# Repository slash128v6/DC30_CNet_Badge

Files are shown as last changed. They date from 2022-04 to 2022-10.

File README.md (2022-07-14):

DEF CON 30 CompuNet Badge

Check out the Docs folder...

Here is an informational 'BadUSB'course from the creator of the WiFi Duck: https://learnbadusb.com/ (we are not affiliated and we don't make any money on this)



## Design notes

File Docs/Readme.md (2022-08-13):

# Flux Capacitor LED Badge

The Flux Capacitor LED badge features three microcontrollers, nine LEDs and a [SAO port](https://hackaday.com/2019/03/20/introducing-the-shitty-add-on-v1-69bis-standard/) that can be used for daughter boards (add-ons). The top two microcontrollers are Arduino Pro Micros, the bottom controller is an ESP8266 D1 Mini with Wifi capabilites. See the appendix for pinouts of each board. 

Looking at the back of the board (battery side) the Pro Micro on the left side will be programmed to control the LED lights. The Pro Micro on the right and the D1 Mini are used as a functioning [Wifi Duck](https://wifiduck.com/).

###Front of Badge:

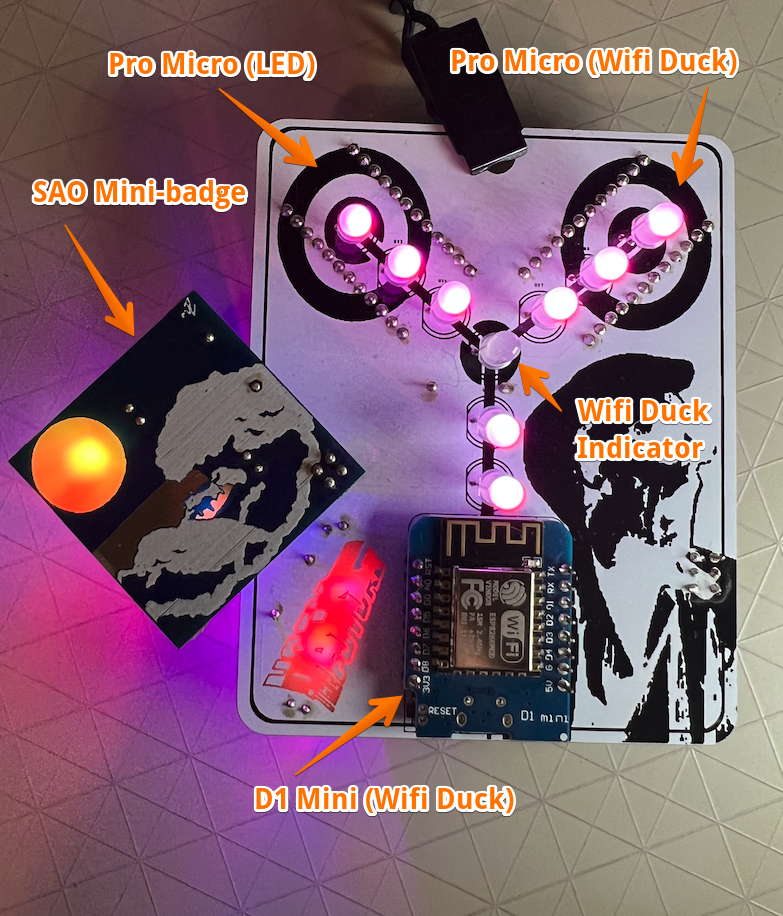
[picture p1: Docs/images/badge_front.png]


###Back of Badge:

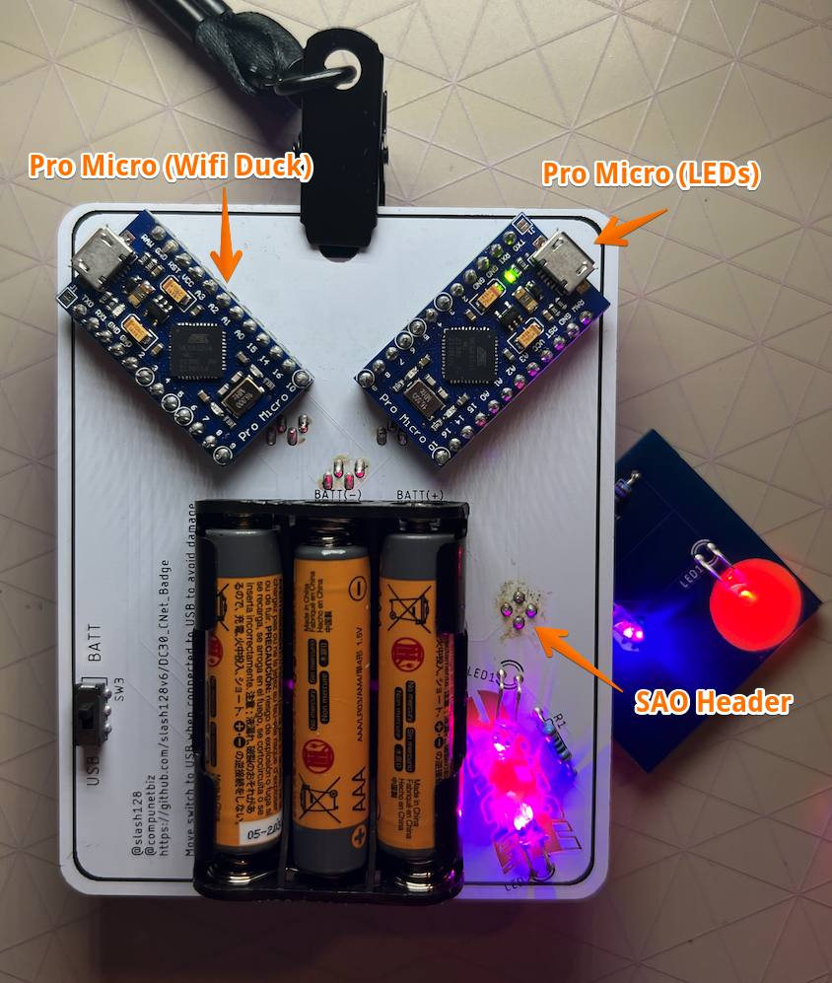
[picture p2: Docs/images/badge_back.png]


## GitHub: [https://github.com/slash128v6/DC30\_CNet\_Badge](https://github.com/slash128v6/DC30_CNet_Badge)

### Parts List

**Main Badge**

- 1 main PCB (white)
- 1 foam pad
- 3 AAA batteries
- 1 battery carrier
- 2 Pro Micro
- 1 D1 Mini
- 1 jumper socket (four pin)
- 1 on/off switch
- 1 100ohm resistor
- 9 RGB LED (larger) F5-F
- 2 RGB LED (smaller - slow cycle) PN 1196
- 1 large static bag

**Mini Badge**

- 1 aux PCB (blue)
- 1 RGB LED (smaller - slow cycle) PN 1196
- 1 RGB LED (smaller - fast cycle) PN 1197 - behind cow
- 1 jumper header (four pin)
- 1 100ohm resistor
- 1 small static bag

# Instructions

## Main Badge

### Step 1: Verify the slow-cycling LEDs (mini-badge uses fast-cycling LED)

The main badge uses 9 large RGB LEDS (with four legs) and 2 smaller slow-cycling RGB LEDs. The mini-badge uses 1 slow-cycling LED and 1 fast-cycling LED that is identical in size and shape to the slow-cycling LEDs. You can verify that you are using the correct LED by testing with the battery pack. The fast-cycling RGB will change color very rapidly - if the colors change gradually, you're using the correct LEDs for the main badge. These LEDs are internally current limited so you can test by connecting it to the battery pack as shown with the longer lead to the left (+ or anode). Do not test regular LEDs like this, they will fry. Even though they don't need a resistor do not connect them backwards or they will fry. Set aside the fast-cycling LED. The other 3 are slow-cycling LEDs.

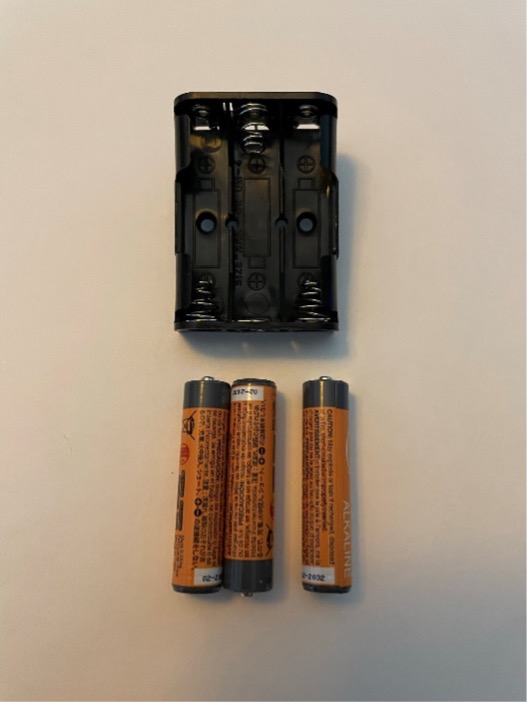
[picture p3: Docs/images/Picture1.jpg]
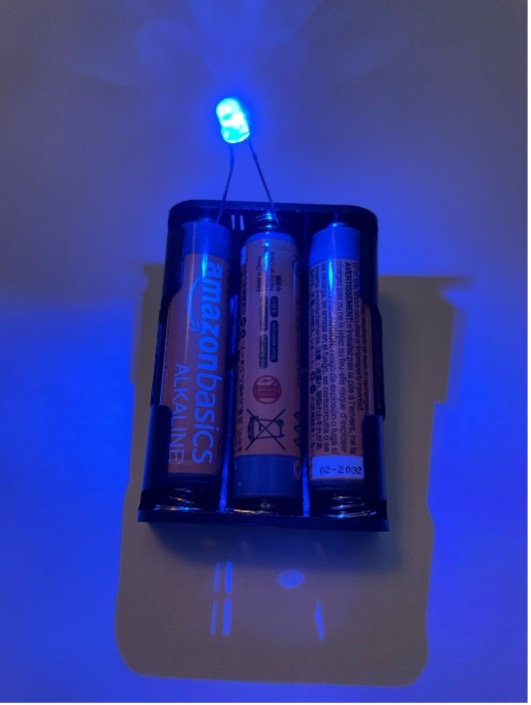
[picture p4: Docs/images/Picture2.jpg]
 

With the board upside down (silkscreen facing down), solder 2 of the slow-cycling rear LEDs on the back with short lead (- cathode) on the left side, and  flat facing label LED1 & LED2. Bend the LEDs so they are flat against the back of the board to shine through the translucent area on the PCB. Solder R1 on the back. Trim the leads on the front.

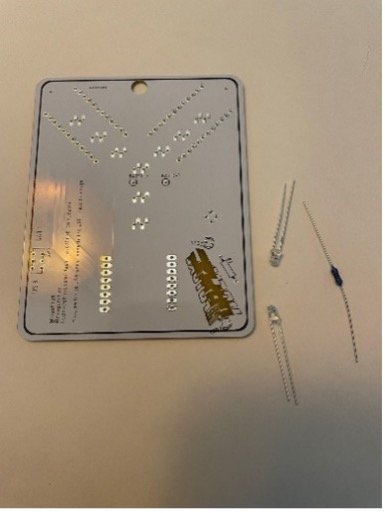
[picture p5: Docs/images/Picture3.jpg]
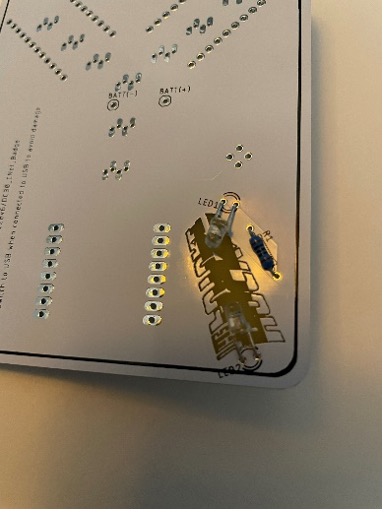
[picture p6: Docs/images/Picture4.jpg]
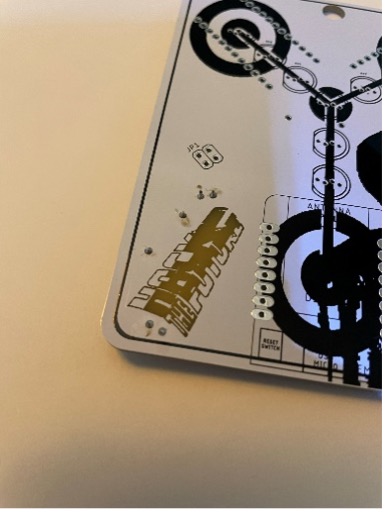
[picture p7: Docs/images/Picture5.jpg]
 

### Step 2: Solder the switch and female header

Solder the switch on the back

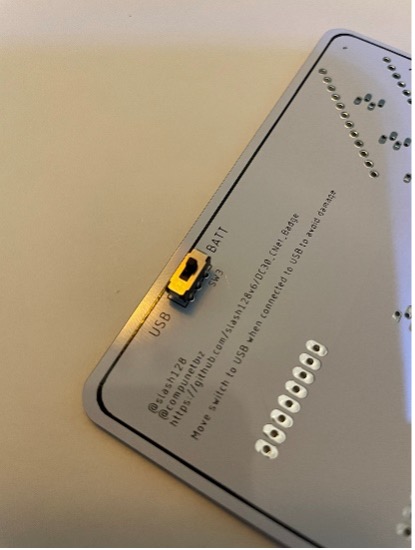
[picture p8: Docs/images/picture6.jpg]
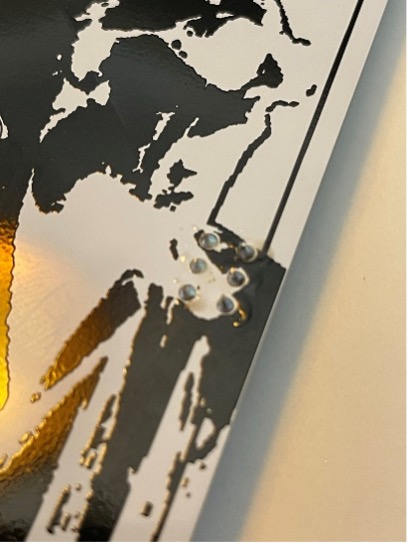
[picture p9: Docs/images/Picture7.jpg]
 

Flip the PCB over to the front and solder the SAO 4 pin female header on the front in position JP1

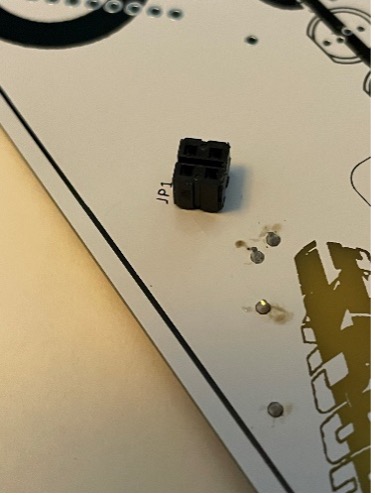
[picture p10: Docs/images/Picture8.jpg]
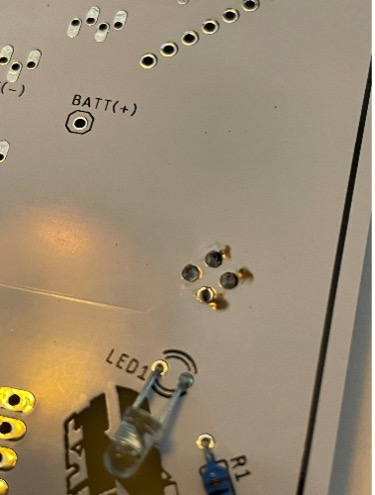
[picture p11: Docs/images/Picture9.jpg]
 

### Step 3: Install front RGB Leds

Install front RGB LEDs with long leads and flat on the left, matching the symbol on the board. Do not push all the way in, stop at the marks on the leads. Make sure there are no solder bridges. Trim the leads so there is clearance for the micro controllers to install on the other side.

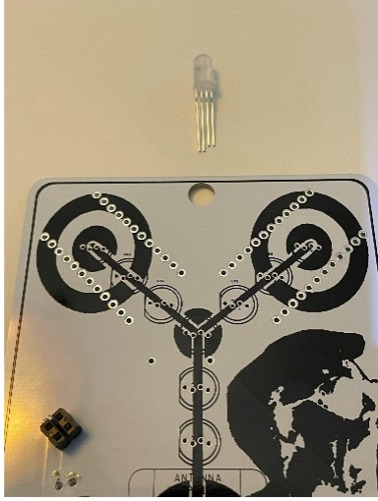
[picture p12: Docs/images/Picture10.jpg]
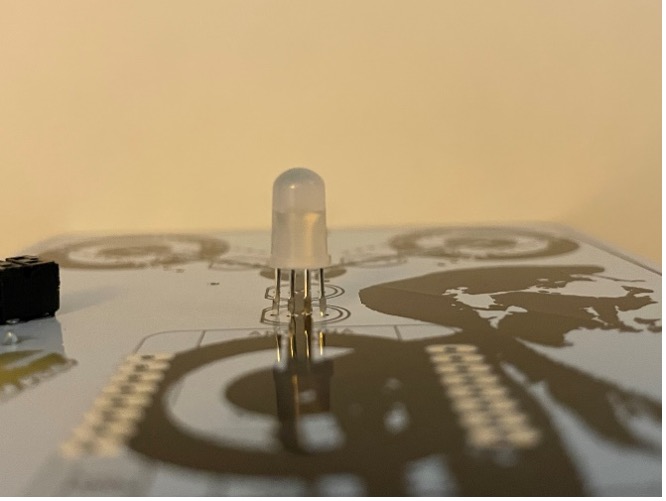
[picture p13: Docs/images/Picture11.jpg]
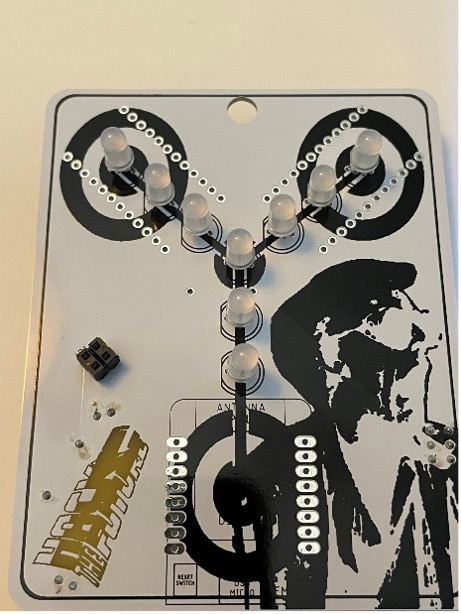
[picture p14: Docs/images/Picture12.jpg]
 

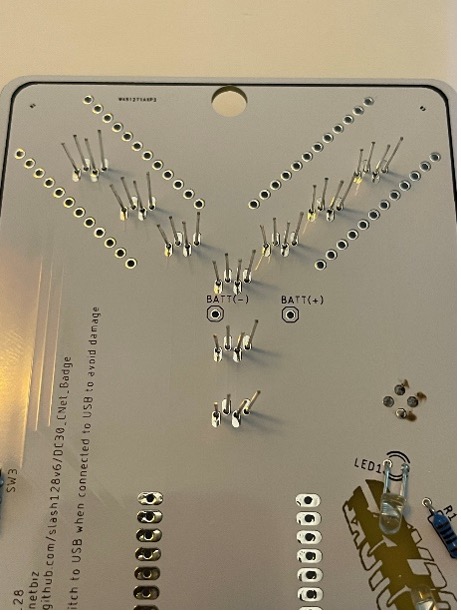
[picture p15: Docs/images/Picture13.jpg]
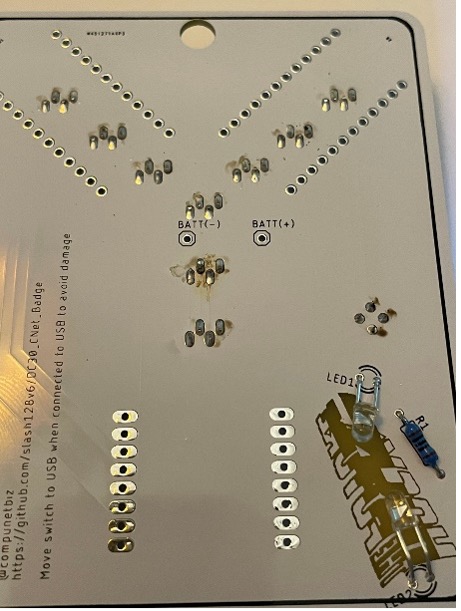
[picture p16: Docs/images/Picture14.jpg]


### Step 4: Install the Pro Micros

Rear View – The Pro Micro boards are identical until they are programmed. Functionally, the WiFi Duck Pro Micro is on the left, LED Pro Micro is on the right. Install with USB connector at the top and facing up away from the board. Install headers with long side facing away from the badge, black insulator between the micro and badge board. Make sure to solder all the pins on both the badge board and micro board.

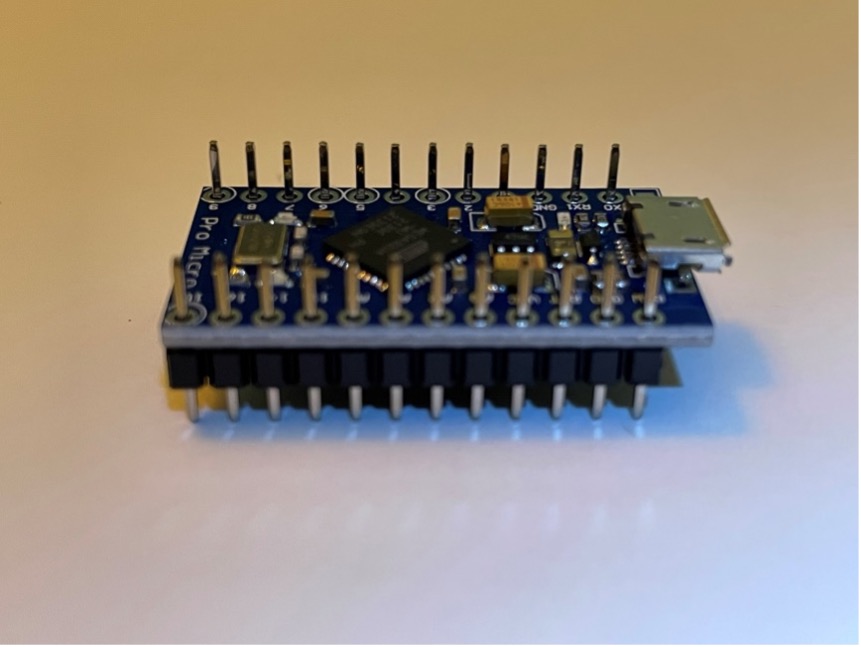
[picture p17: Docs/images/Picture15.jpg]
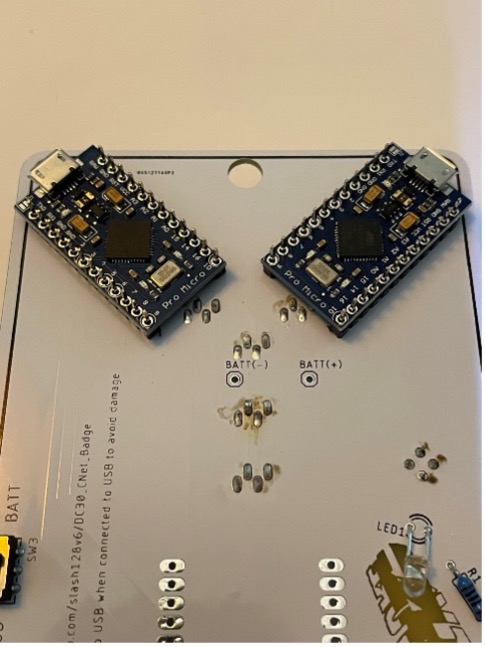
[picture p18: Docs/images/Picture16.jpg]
 

### Step 5: Install the D1 Mini

Front View – D1 Mini. Install with reset button on the left and USB connector at the bottom facing down towards the board. Install headers with long side facing away from the badge, black insulator between the micro and badge board.

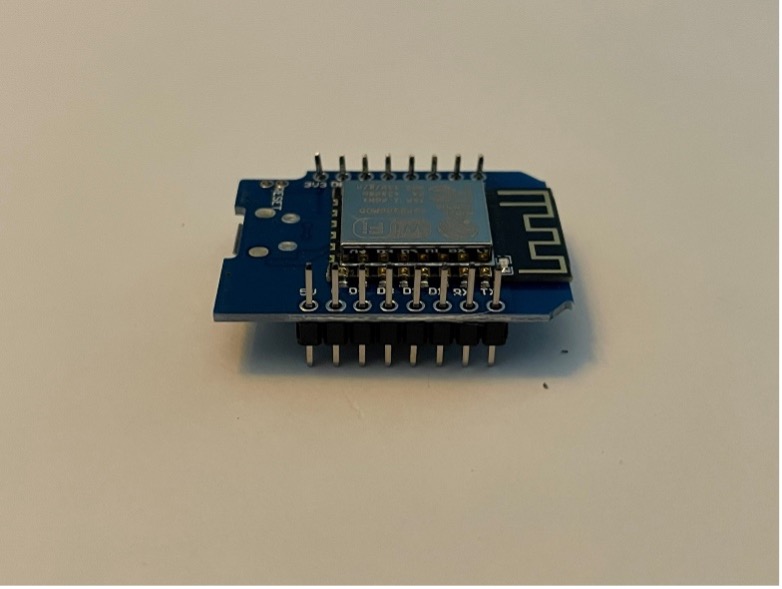
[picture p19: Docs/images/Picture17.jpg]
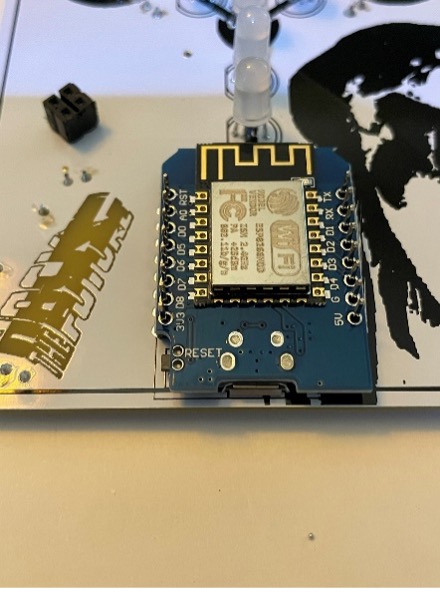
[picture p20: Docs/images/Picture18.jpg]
 

Trim a piece of double-sided foam tape to fit between the pins of the D1 Mini on back, then place battery holder on tape and solder the leads on the front

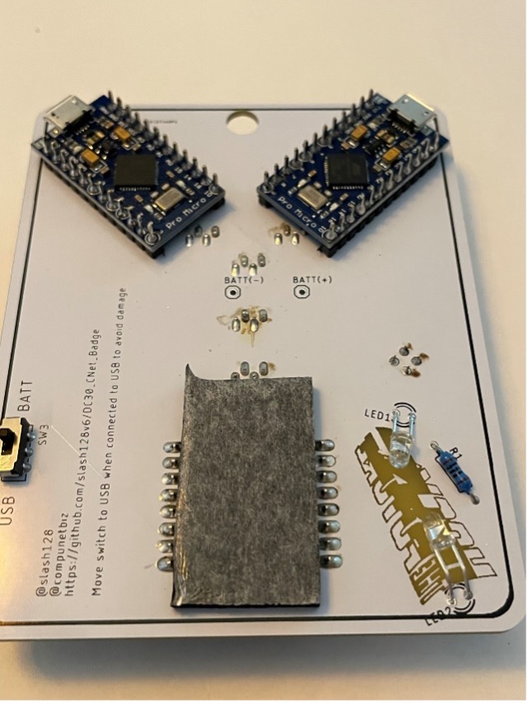
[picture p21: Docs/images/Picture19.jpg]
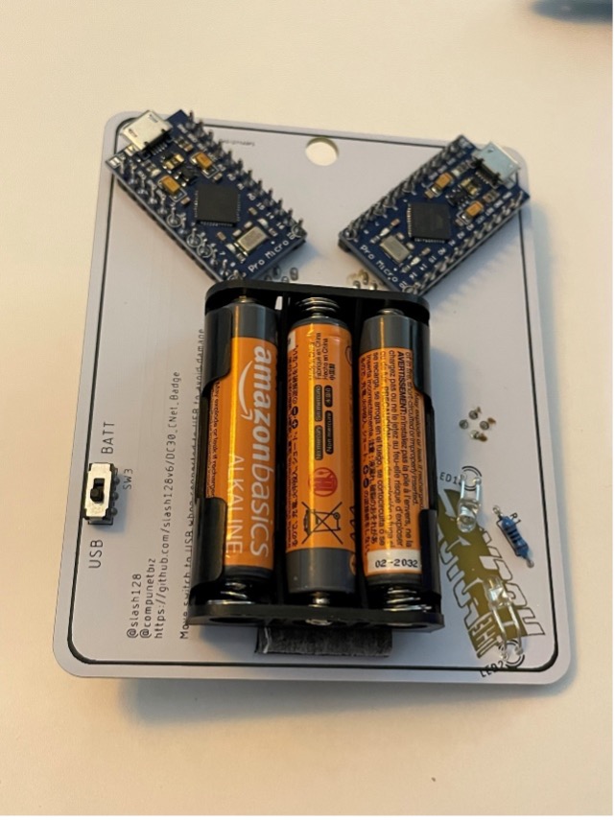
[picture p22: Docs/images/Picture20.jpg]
 

Slide switch to BATT for battery mode and USB when connecting to USB. Do not leave switch in BATT mode when USB power is connected.

## SAO: Mini-badge

Solder rear LEDs on the back with short lead and flat facing label LED1 & LED2. Bend the LEDs so they are flat against the back of the board to shine through the clear area on the PCB. The fast-cycling LED goes behind the surfing cow and the slow cycling LED goes behind the sun. Solder R1 on the back. Solder the male 4 pin header on the back. Trim the LED and resistor excess leads on the front.

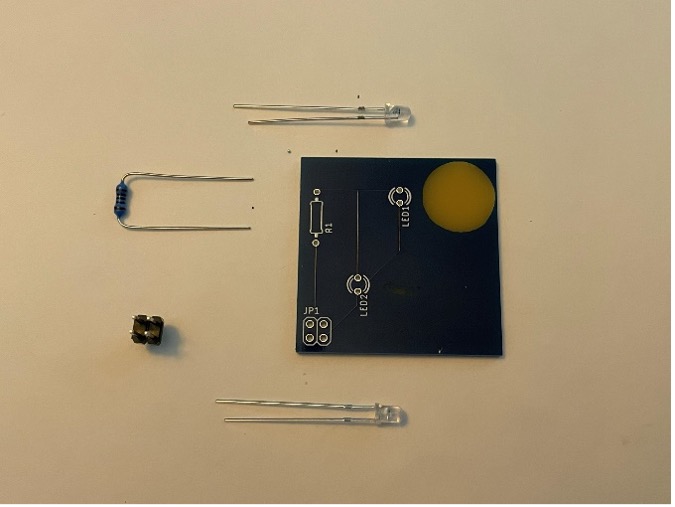
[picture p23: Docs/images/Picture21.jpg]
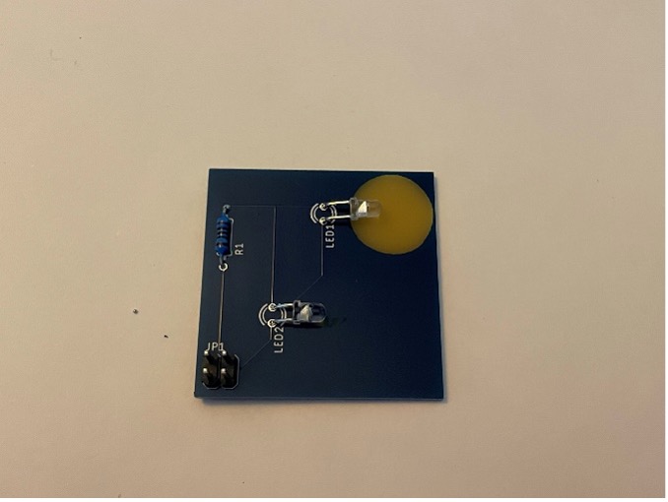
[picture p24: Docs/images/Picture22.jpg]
 

Connect the SAO PCB to the main badge. Slide the switch to BATT and verify the small LEDs on the main badge and SAO all work.

 

## Badge LED Micro Programming

### Setting up the Arduino IDE

#### Download the Arduino IDE: 

[https://www.arduino.cc/en/software](https://www.arduino.cc/en/software)

Open Tools-> Board -> Boards Manager and select type "Contributed". If this is a new installation, you will likely not have "Sparkfun AVR Boards". Copy the following URL:

`https://raw.githubusercontent.com/sparkfun/Arduino_Boards/main/IDE_Board_Manager/package_sparkfun_index.json`

In the Arduino software, click on the Arduino menu and select "Preferences". Paste the URL in the field labled "Additional  Boards URL"



Open Tools-> Board -> Boards Manager and select type "Contributed". You should now see "Sparkfun AVR Boards" as an option. Click Install. Close Boards Manager when the install is complete.



**Now select the correct board: Tools -> Board -> Sparkfun AVR Boards -> Sparkfun Pro Micro**

**Select the correct processor: 5v, 16mhz**



Connect a data micro USB cable to the right Pro Micro on the back of the badge.



Download the LED Micro .ino file from the repo and open in Arduino: [https://github.com/slash128v6/DC30\_CNet\_Badge/blob/main/DC30\_CNet\_Badge/DC30\_CNet\_Badge.ino](https://github.com/slash128v6/DC30_CNet_Badge/blob/main/DC30_CNet_Badge/DC30_CNet_Badge.ino)

*Make sure you select the SparkFun Pro Micro from the SparkFun boards and Processor is the 5V, 16MHz version. If you select the 3V version and try to upload you’ll have to follow the recover process from SparkFun to unbrick it.*

**New Arduino installations will need to install the Neopixel library before the sketch updloads correctly.**



To install the missing Neopixal library, open Library Manager:

Sketch -> Include Library -> Manage Libraries

In the Library Manager, search for Adafruit Neopixel and click install:



With the Neopixel library installed, you should be able to upload the .ino file to the badge. Once uploaded, the LEDs on the front should start cycling. The front center RGB LED is for the WiFi Duck and does not light up with the other LEDs. See the WiFi Duck scripting documentation for use.



# WiFi Duck

The front center RGB LED is for the WiFi Duck and does not light up with the other LEDs. See the WiFi Duck scripting documentation for use.
The WiFi Duck uses the D1 Mini on the front and the Pro Micro on the back left side.

 

Follow the guide on the WiFi Duck GitHub for uploading firmware: https://github.com/SpacehuhnTech/WiFiDuck

**Make sure to use the correct board settings from the WiFi Duck boards and also make sure Debug is Disabled and Protocol is set to I2C for both the WiFi AVR Micro and D1 Mini. Neopixel on Pin 7.**

 

With the WiFi Duck powered by USB (either D1 Miini or Pro Micro) connect to WiFi network “wifiduck” with password “wifiduck” and open a browser window to http://192.168.4.1. Create a script called rickroll.script.



Paste the contents of rickroll.script file into the Editor, click Save and Enable Autorun.



With the USB cable connected to your PC and the WiFi Duck AVR Micro click the Run button and the script should run. With Autorun enabled the script should autorun when the USB connection is made.



#Appendix
##Pro Micro


##ESP8266 D1 Mini


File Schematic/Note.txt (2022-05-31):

There is an error with the old RGB Addressable LED symbol. The schematic connections were made so that the board would work.

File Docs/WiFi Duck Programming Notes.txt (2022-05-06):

See the WiFiDuck Documentation for Arduino IDE configuration, libraries, boards, etc.: WiFi Duck GitHub: https://github.com/SpacehuhnTech/WiFiDuck
Use the DSTIKE Boards: Spark Fun Pro Micro 5V and Wemos D1 Mini
Set protocol to I2C
Disable Debugging
Set NeoPixel to 7


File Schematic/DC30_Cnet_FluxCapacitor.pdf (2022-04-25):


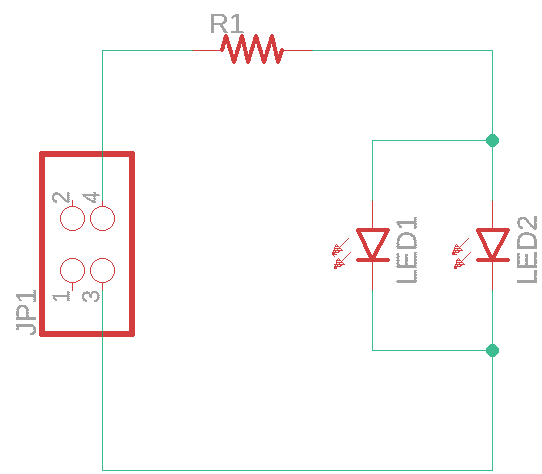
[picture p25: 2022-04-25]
Schematic/DC30_Cnet_Cow-A-Bunga_SAO.png

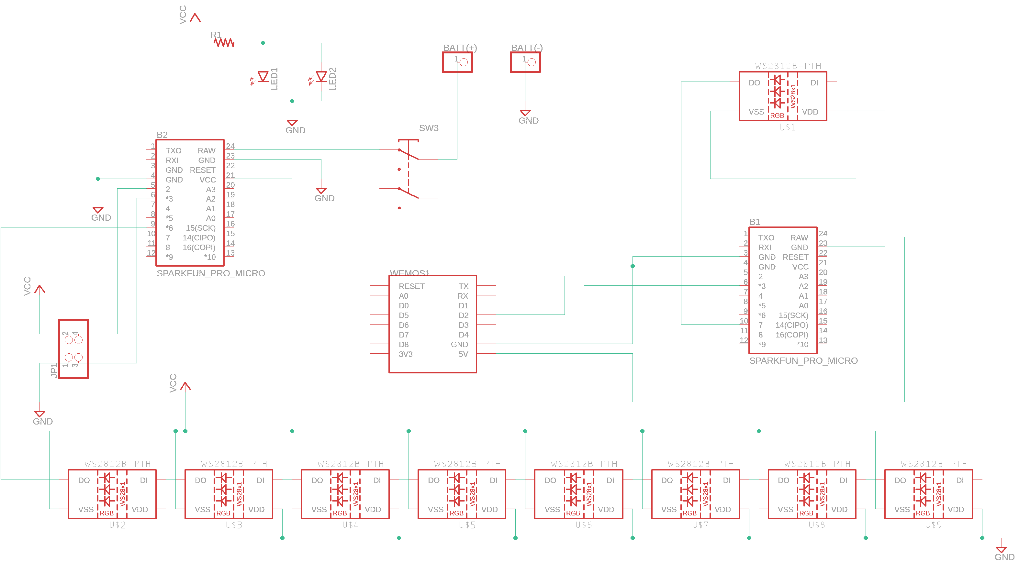
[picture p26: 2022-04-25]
Schematic/DC30_Cnet_FluxCapacitor.png

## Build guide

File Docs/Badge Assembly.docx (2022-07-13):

Flux Capacitor LED Badge - GitHub: https://github.com/slash128v6/DC30_CNet_Badge

One of the 4 small LEDs is a fast-cycling LED. These LEDs are internally current limited so you can test by connecting it to the battery pack as shown with the longer lead to the left. Do not test regular LEDs like this, they will fry. Set aside the fast-cycling LED. The other 3 are slow-cycling LEDs.

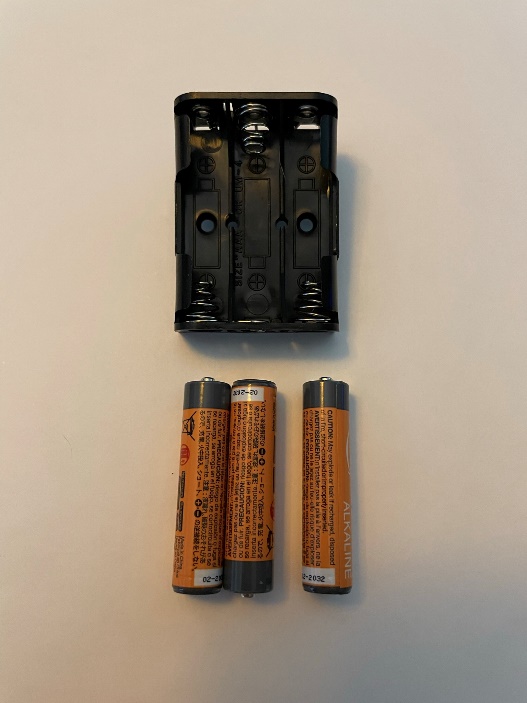
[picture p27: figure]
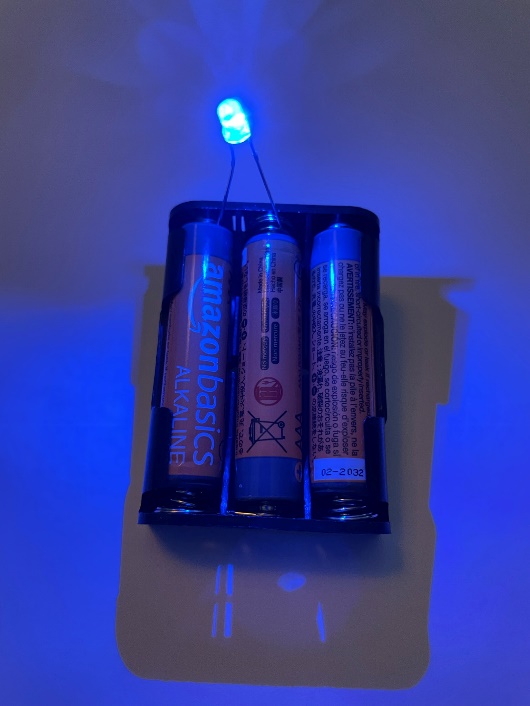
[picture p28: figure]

Solder 2 of the slow-cycling rear LEDs on the back with short lead and flat facing label LED1 & LED2. Bend the LEDs so they are flat against the back of the board to shine through the translucent area on the PCB. Solder R1 on the back. Trim the leads on the front.

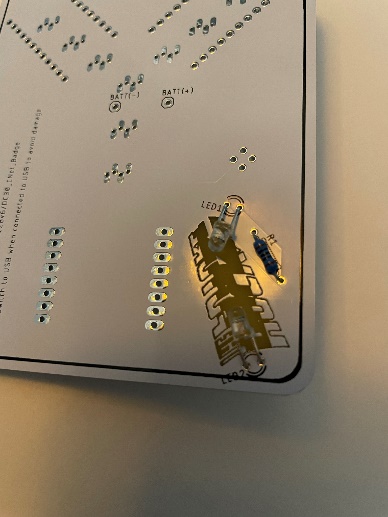
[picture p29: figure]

Solder the switch on the back.

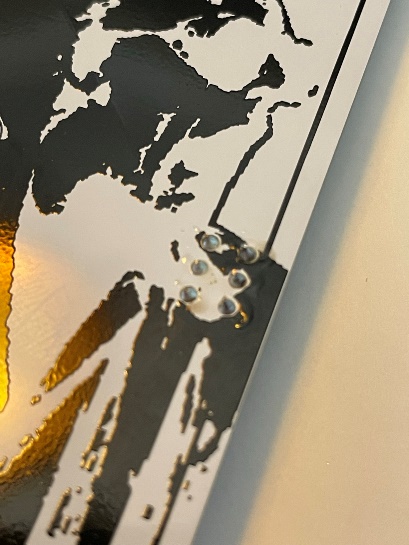
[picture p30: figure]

Solder the SAO 4 pin female header on the front.

Install front RGB LEDs with long leads and flat on the left, matching the symbol on the board. Do not push all the way in, stop at the marks on the leads. Make sure there are no solder bridges. Trim the leads so there is clearance for the micro controllers to install on the other side.

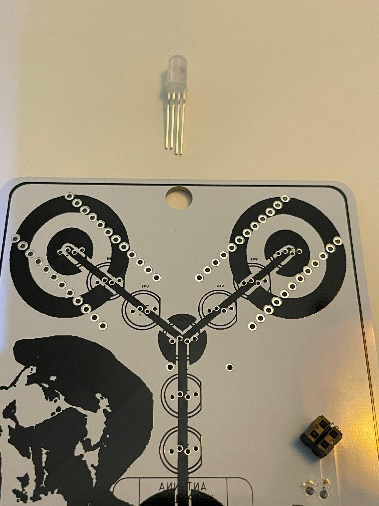
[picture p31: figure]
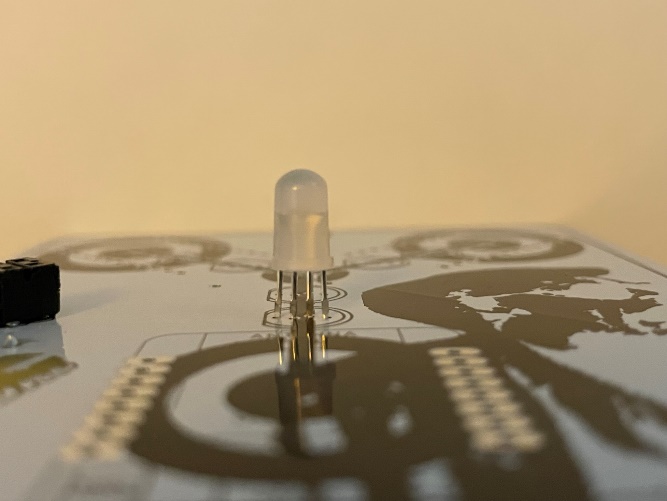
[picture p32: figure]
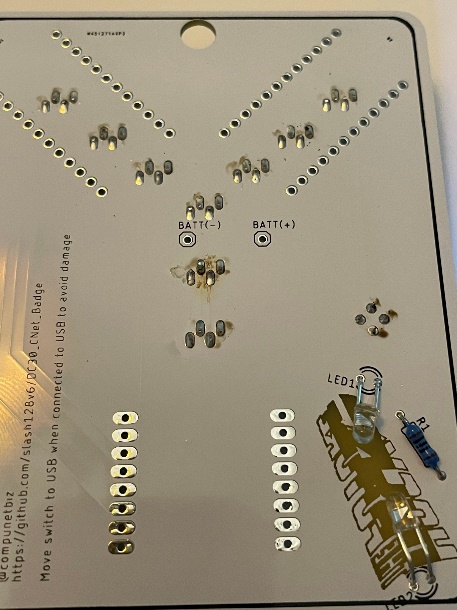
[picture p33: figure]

Rear View – WiFi Duck Pro Micro is on the left, LED Pro Micro is on the right. Install with USB connector at the top and facing up away from the board. Install headers with long side facing away from the badge, black insulator between the micro and badge board. Make sure to solder all the pins on both the badge board and micro board.

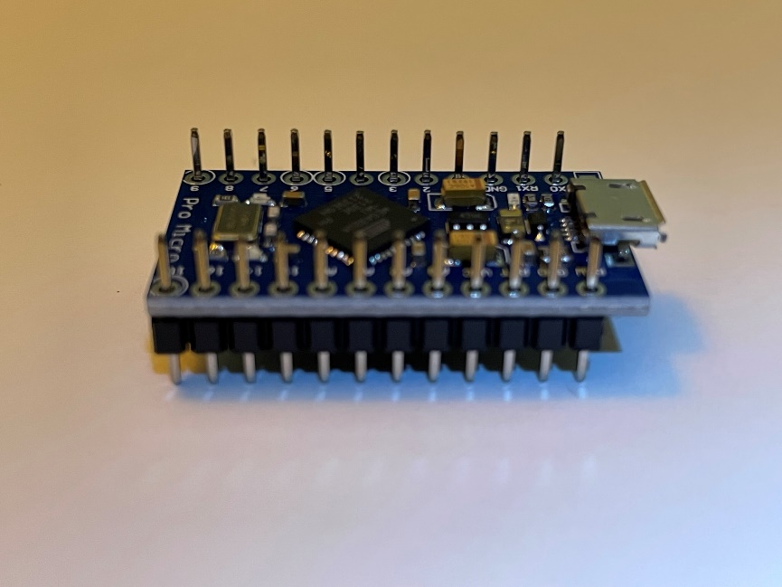
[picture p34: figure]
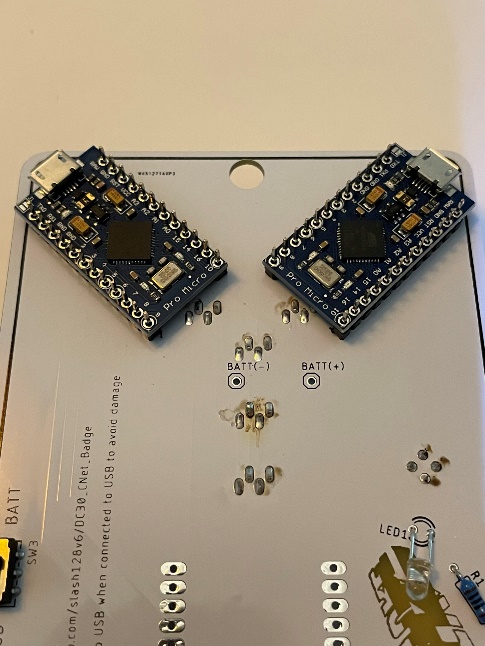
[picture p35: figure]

Front View – D1 Mini. Install with reset button on the left and USB connector at the bottom facing down towards the board. Install headers with long side facing away from the badge, black insulator between the micro and badge board.

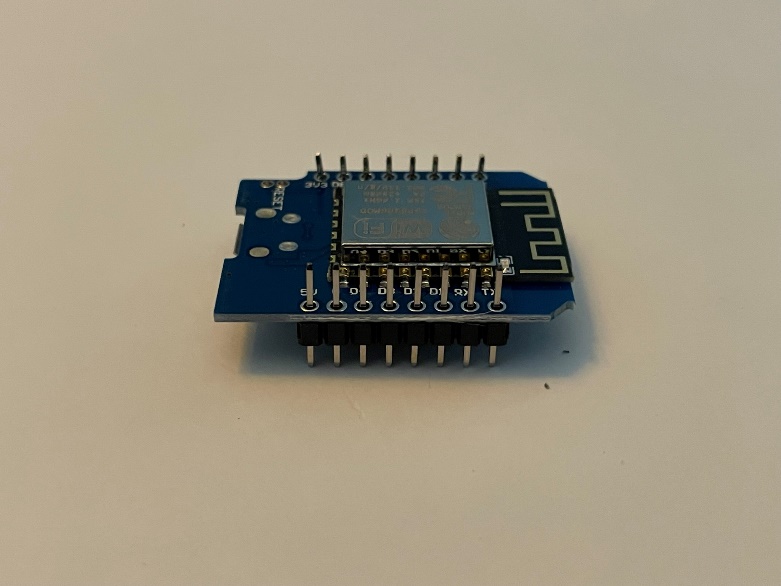
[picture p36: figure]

Trim a piece of double-sided foam tape to fit between the pins of the D1 Mini on back, then place battery holder on tape and solder the leads on the front

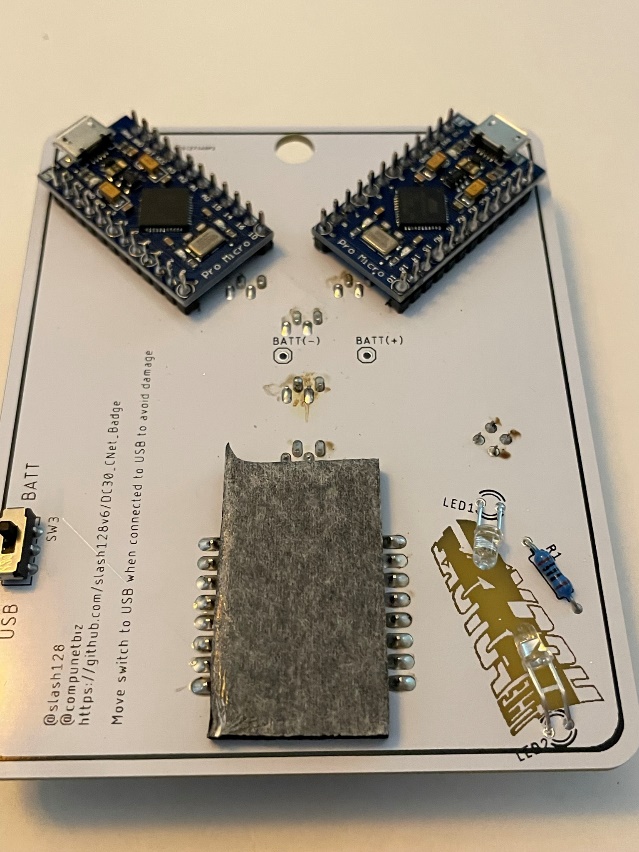
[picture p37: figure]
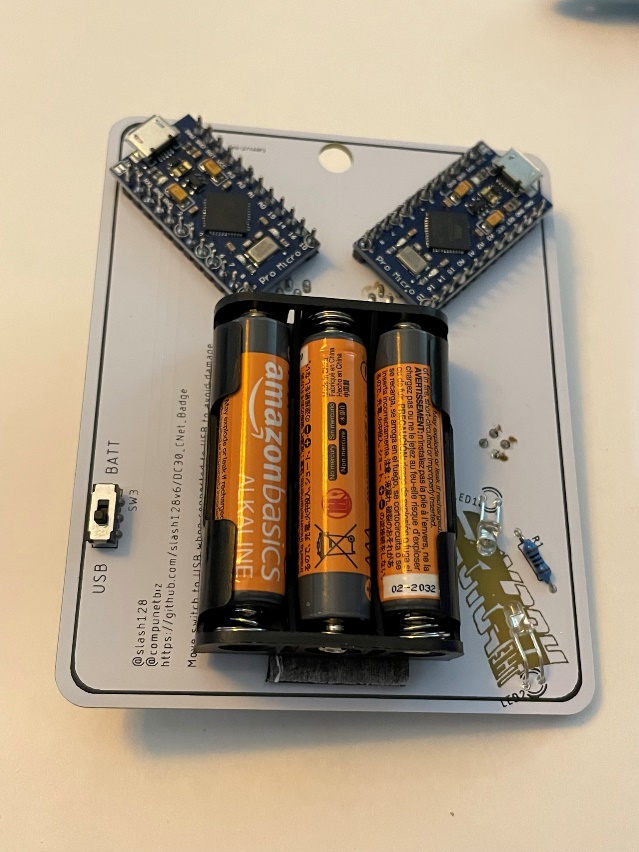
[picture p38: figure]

Slide switch to BATT for battery mode and USB when connecting to USB. Do not leave switch in BATT mode when USB power is connected.

SAO

Solder rear LEDs on the back with short lead and flat facing label LED1 & LED2. Bend the LEDs so they are flat against the back of the board to shine through the clear area on the PCB. The fast-cycling LED goes behind the surfing cow and the slow cycling LED goes behind the sun. Solder R1 on the back. Solder the male 4 pin header on the back. Trim the LED and resistor excess leads on the front.

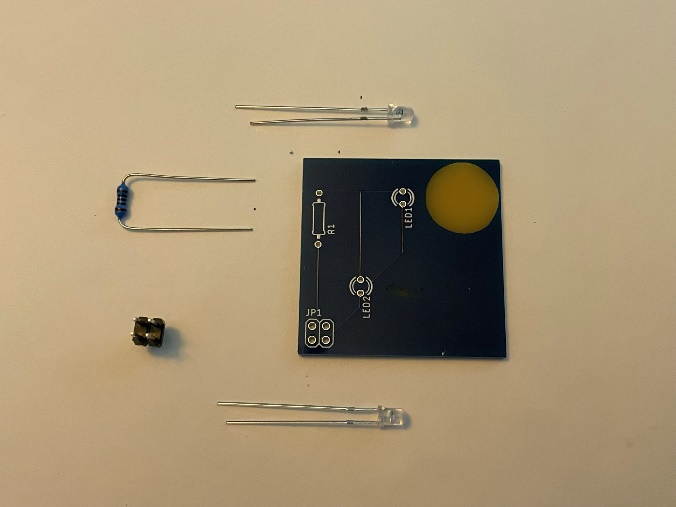
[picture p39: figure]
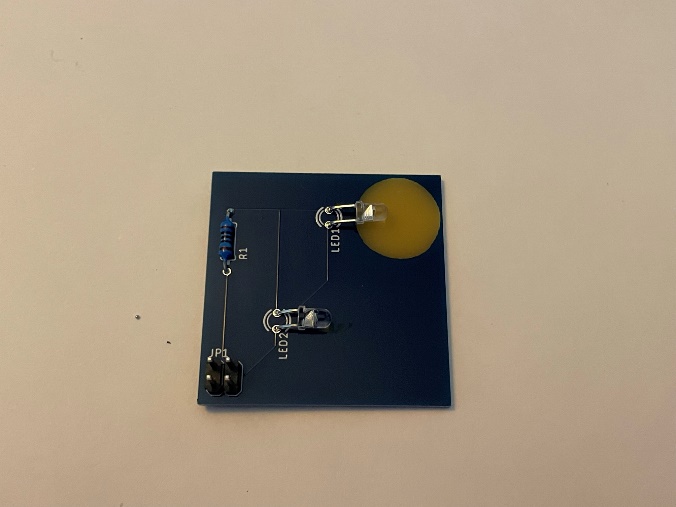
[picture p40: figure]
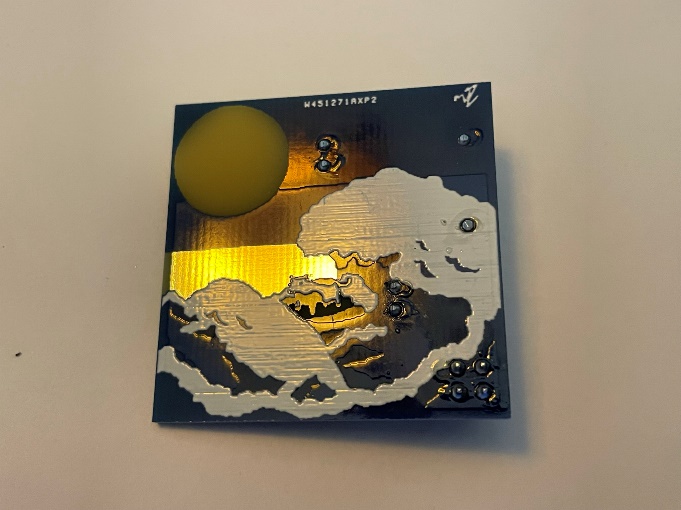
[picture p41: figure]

Connect the SAO PCB to the main badge. Slide the switch to BATT and verify the small LEDs on the main badge and SAO all work.

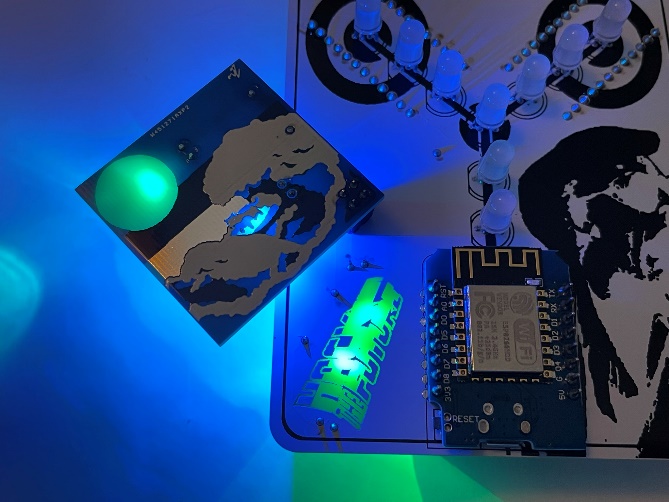
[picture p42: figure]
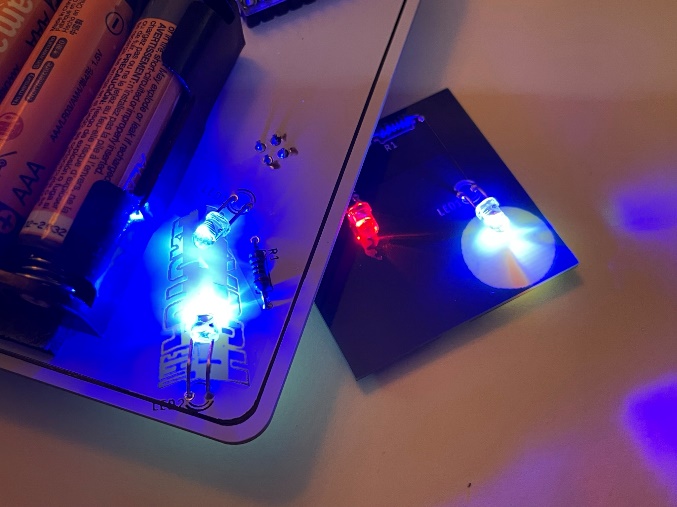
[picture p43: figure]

Badge LED Micro Programming

Load the SparkFun Pro Micro board in Board Manager in the Arduino IDE:

https://www.sparkfun.com/products/12640

Connect a data micro USB cable to the right Pro Micro on the back of the badge.

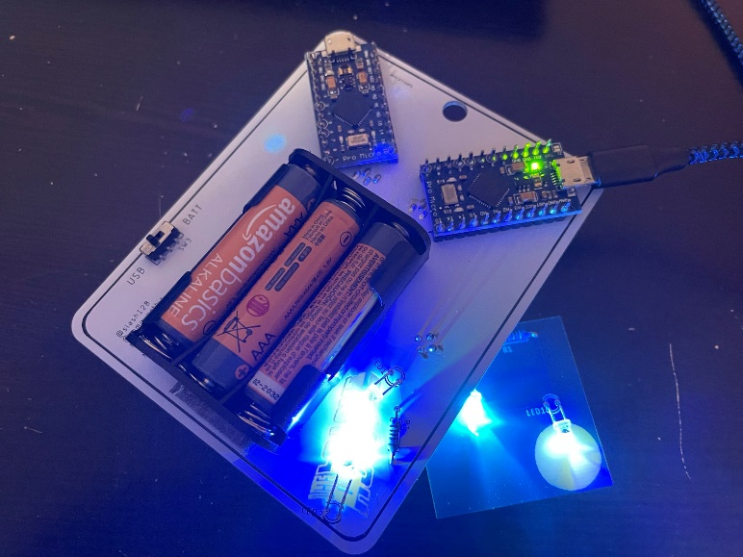
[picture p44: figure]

Download the LED Micro .ino file from the repo and open in Arduino: https://github.com/slash128v6/DC30_CNet_Badge/blob/main/DC30_CNet_Badge/DC30_CNet_Badge.ino

Make sure you select the SparkFun Pro Micro from the SparkFun boards and Processor is the 5V, 16MHz version. If you select the 3V version and try to upload you’ll have to follow the recover process from SparkFun to unbrick it.

Once you have all your settings correct and port selected upload the file and then the LEDs on the front should start cycling. The front center RGB LED is for the WiFi Duck and does not light up with the other LEDs. See the WiFi Duck scripting documentation for use.

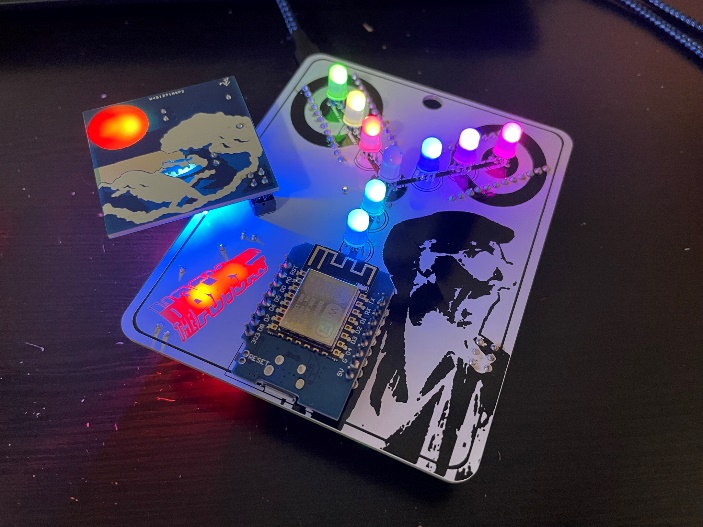
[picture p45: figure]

WiFi Duck

The front center RGB LED is for the WiFi Duck and does not light up with the other LEDs. See the WiFi Duck scripting documentation for use.

The WiFi Duck uses the D1 Mini on the front and the Pro Micro on the back left side.

Follow the guide on the WiFi Duck GitHub for uploading firmware: https://github.com/SpacehuhnTech/WiFiDuck

Make sure to use the correct board settings from the WiFi Duck boards and also make sure Debug is Disabled and Protocol is set to I2C for both the WiFi AVR Micro and D1 Mini. Neopixel on Pin 7.

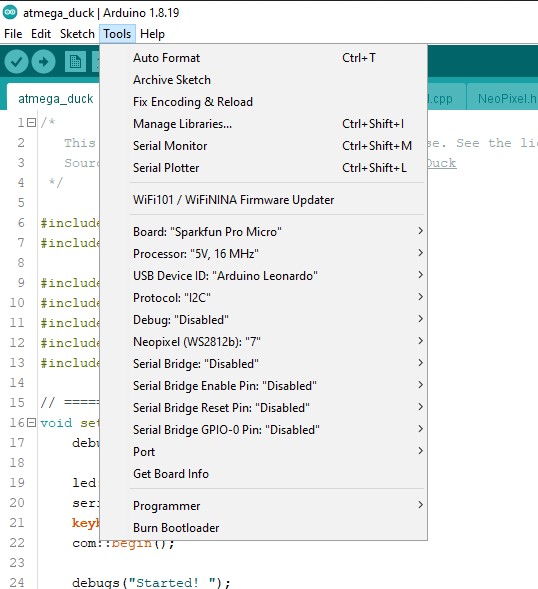
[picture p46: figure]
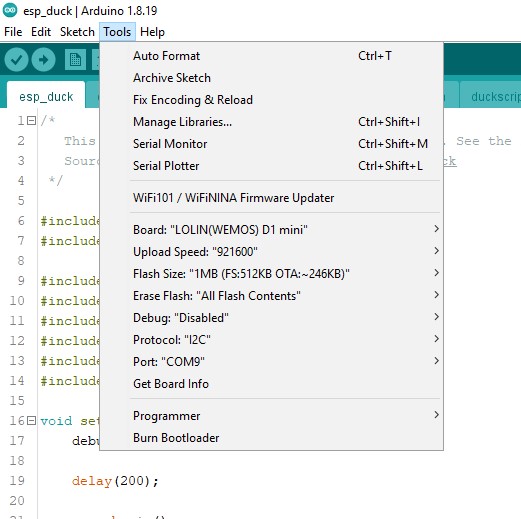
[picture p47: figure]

With the WiFi Duck powered by USB (either D1 Miini or Pro Micro) connect to WiFi network “wifiduck” with password “wifiduck” and open a browser window to http://192.168.4.1. Create a script called rickroll.script.

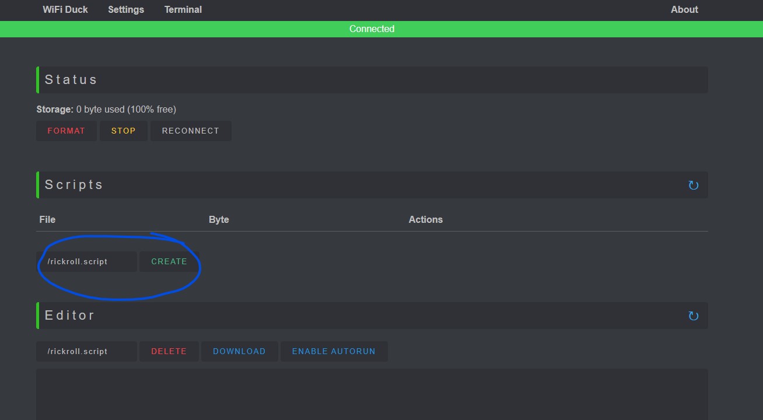
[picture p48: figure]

Paste the contents of rickroll.script file into the Editor, click Save and Enable Autorun.

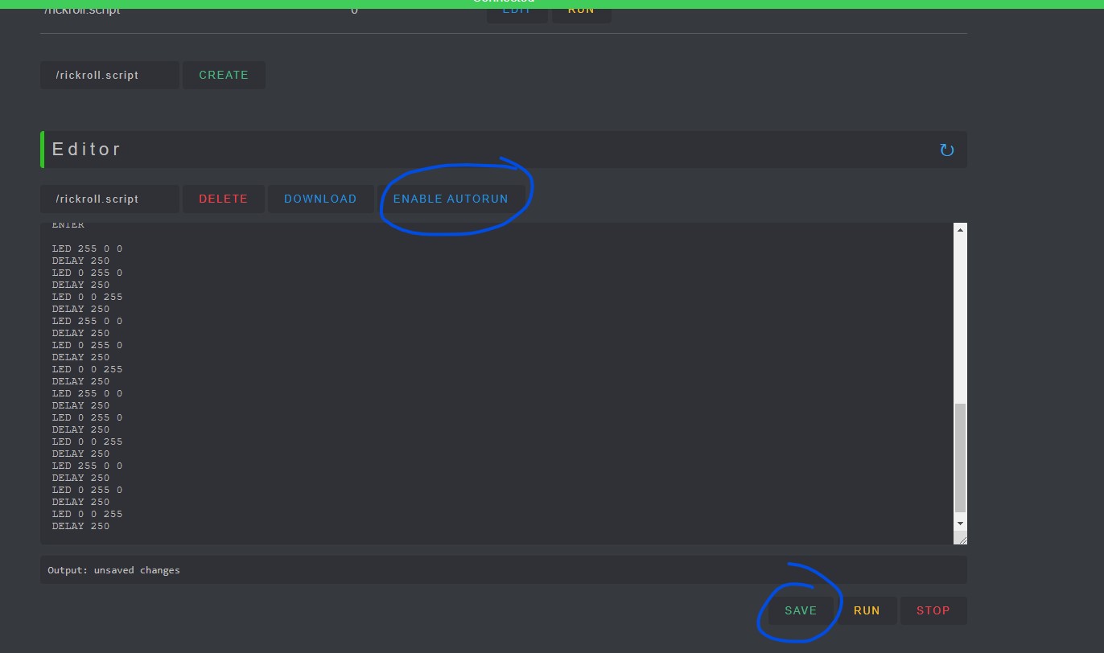
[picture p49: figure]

With the USB cable connected to your PC and the WiFi Duck AVR Micro click the Run button and the script should run. With Autorun enabled the script should autorun when the USB connection is made.

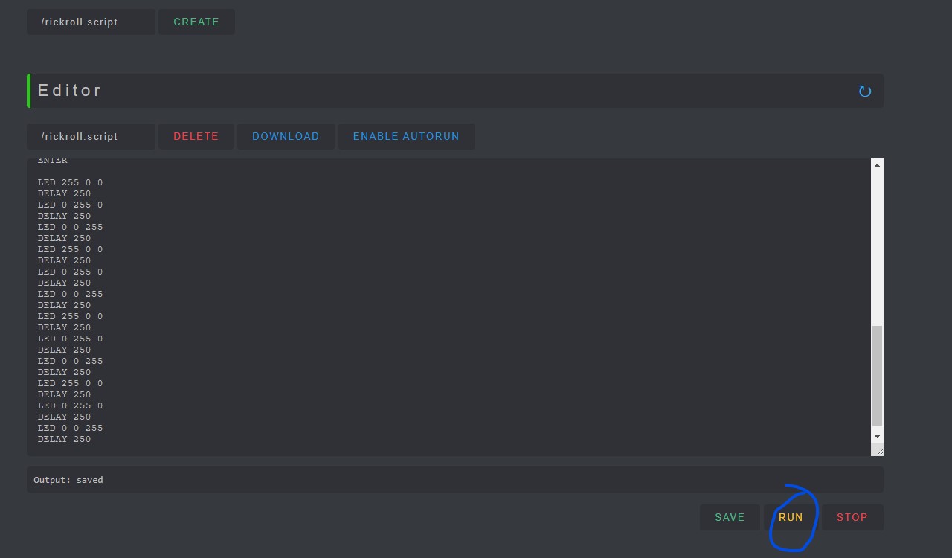
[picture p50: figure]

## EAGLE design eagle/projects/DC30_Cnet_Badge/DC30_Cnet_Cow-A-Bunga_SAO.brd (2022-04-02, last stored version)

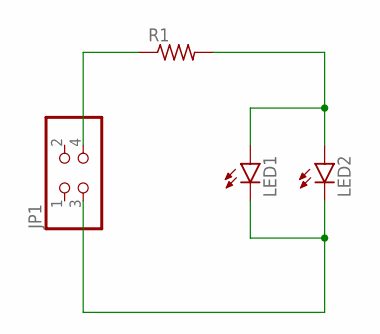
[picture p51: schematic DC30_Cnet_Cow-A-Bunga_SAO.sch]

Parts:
JP1: PINHD-2X2; 2X02
LED1, LED2: LED3MM
R1: R-US_R0805; R0805

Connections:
unnamed: JP1.3, LED1.K (C), LED2.K (C)
unnamed: JP1.4, R1.1
unnamed: LED1.A, LED2.A, R1.2

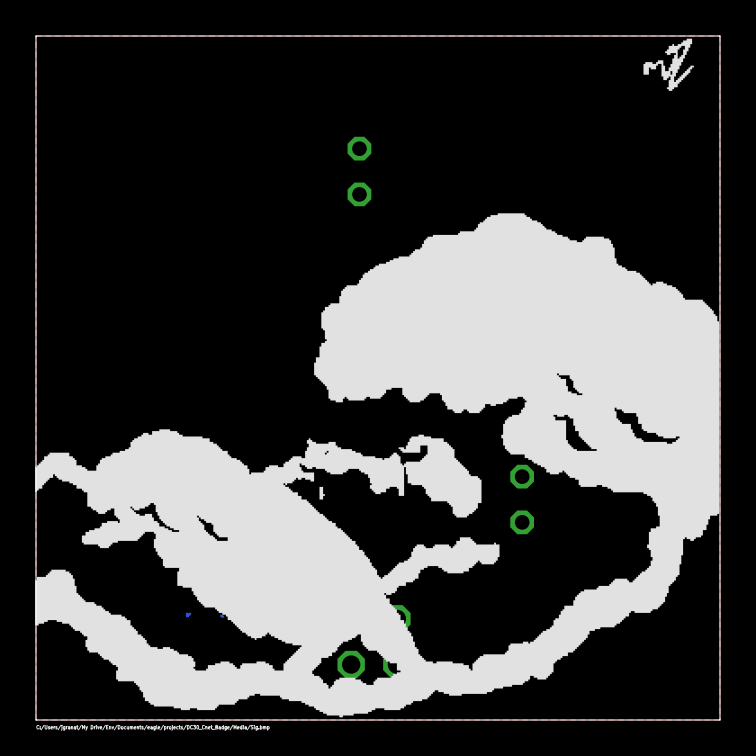
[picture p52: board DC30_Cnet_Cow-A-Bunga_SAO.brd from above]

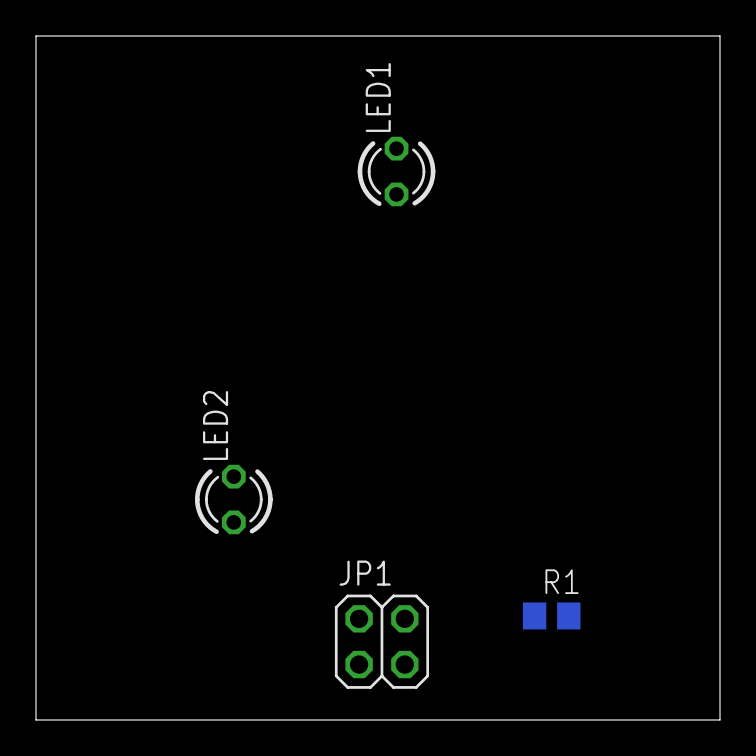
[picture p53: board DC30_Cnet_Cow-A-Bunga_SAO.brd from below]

Board: 2 copper layers, 38.0 x 38.0 mm, 4 parts (4 on the bottom side), 3 nets.

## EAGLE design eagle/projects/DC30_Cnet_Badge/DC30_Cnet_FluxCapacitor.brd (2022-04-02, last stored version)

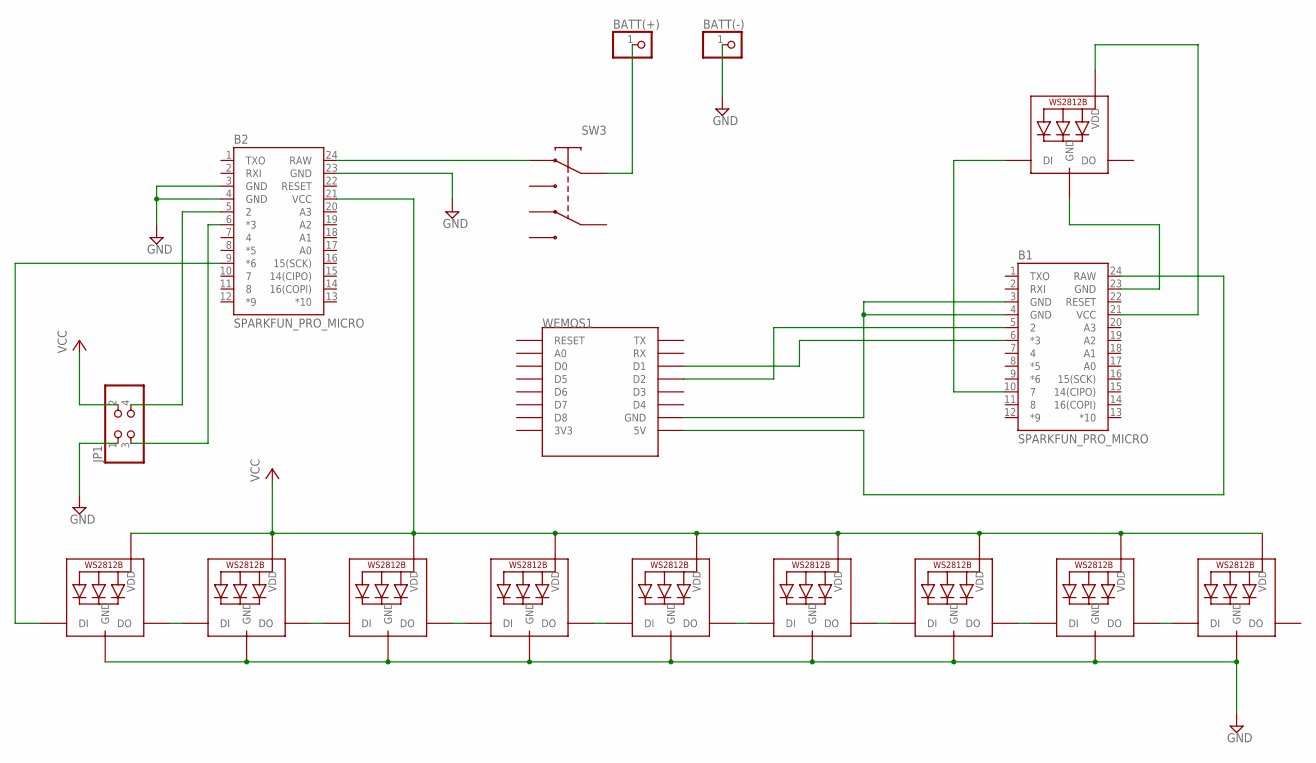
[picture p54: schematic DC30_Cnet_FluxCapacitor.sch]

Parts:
B1, B2: SPARKFUN_PRO_MICRO
BATT(+): PINHD-1X1; 1X01
BATT(-): PINHD-1X1; 1X01
JP1: PINHD-2X2; 2X02
LED1, LED2, LED3, LED4, LED5, LED6, LED7, LED8, LED9, LED10: WS2812B5050; WS2812B
SW3: JS202011AQN
WEMOS1: WEMOS-D1-MINI

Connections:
GND: B2.3 (GND), B2.4 (GND), B2.23 (GND), BATT(-).1, JP1.1, LED1.3-GND (GND), LED2.3-GND (GND), LED3.3-GND (GND), LED4.3-GND (GND), LED5.3-GND (GND), LED6.3-GND (GND), LED7.3-GND (GND), LED8.3-GND (GND), LED9.3-GND (GND)
unnamed: B1.10 (7), LED10.4-DIN (DI)
unnamed: BATT(+).1, SW3.P$2 (2)
unnamed: B2.9 (*6), LED1.4-DIN (DI)
unnamed: LED1.2-DOUT (DO), LED2.4-DIN (DI)
unnamed: LED2.2-DOUT (DO), LED3.4-DIN (DI)
unnamed: LED3.2-DOUT (DO), LED4.4-DIN (DI)
unnamed: LED4.2-DOUT (DO), LED5.4-DIN (DI)
unnamed: LED5.2-DOUT (DO), LED6.4-DIN (DI)
unnamed: LED6.2-DOUT (DO), LED7.4-DIN (DI)
unnamed: LED7.2-DOUT (DO), LED8.4-DIN (DI)
unnamed: LED8.2-DOUT (DO), LED9.4-DIN (DI)
unnamed: B2.5 (2), JP1.4
unnamed: B1.3 (GND), B1.4 (GND), WEMOS1.GND
unnamed: B1.24 (RAW), WEMOS1.5V
unnamed: B1.23 (GND), LED10.3-GND (GND)
unnamed: B1.21 (VCC), LED10.1-VDD (VDD)
unnamed: B1.5 (2), WEMOS1.D2
unnamed: B1.6 (*3), WEMOS1.D1
unnamed: B2.6 (*3), JP1.3
unnamed: B2.24 (RAW), SW3.P$1 (1)
VCC: B2.21 (VCC), JP1.2, LED1.1-VDD (VDD), LED2.1-VDD (VDD), LED3.1-VDD (VDD), LED4.1-VDD (VDD), LED5.1-VDD (VDD), LED6.1-VDD (VDD), LED7.1-VDD (VDD), LED8.1-VDD (VDD), LED9.1-VDD (VDD)

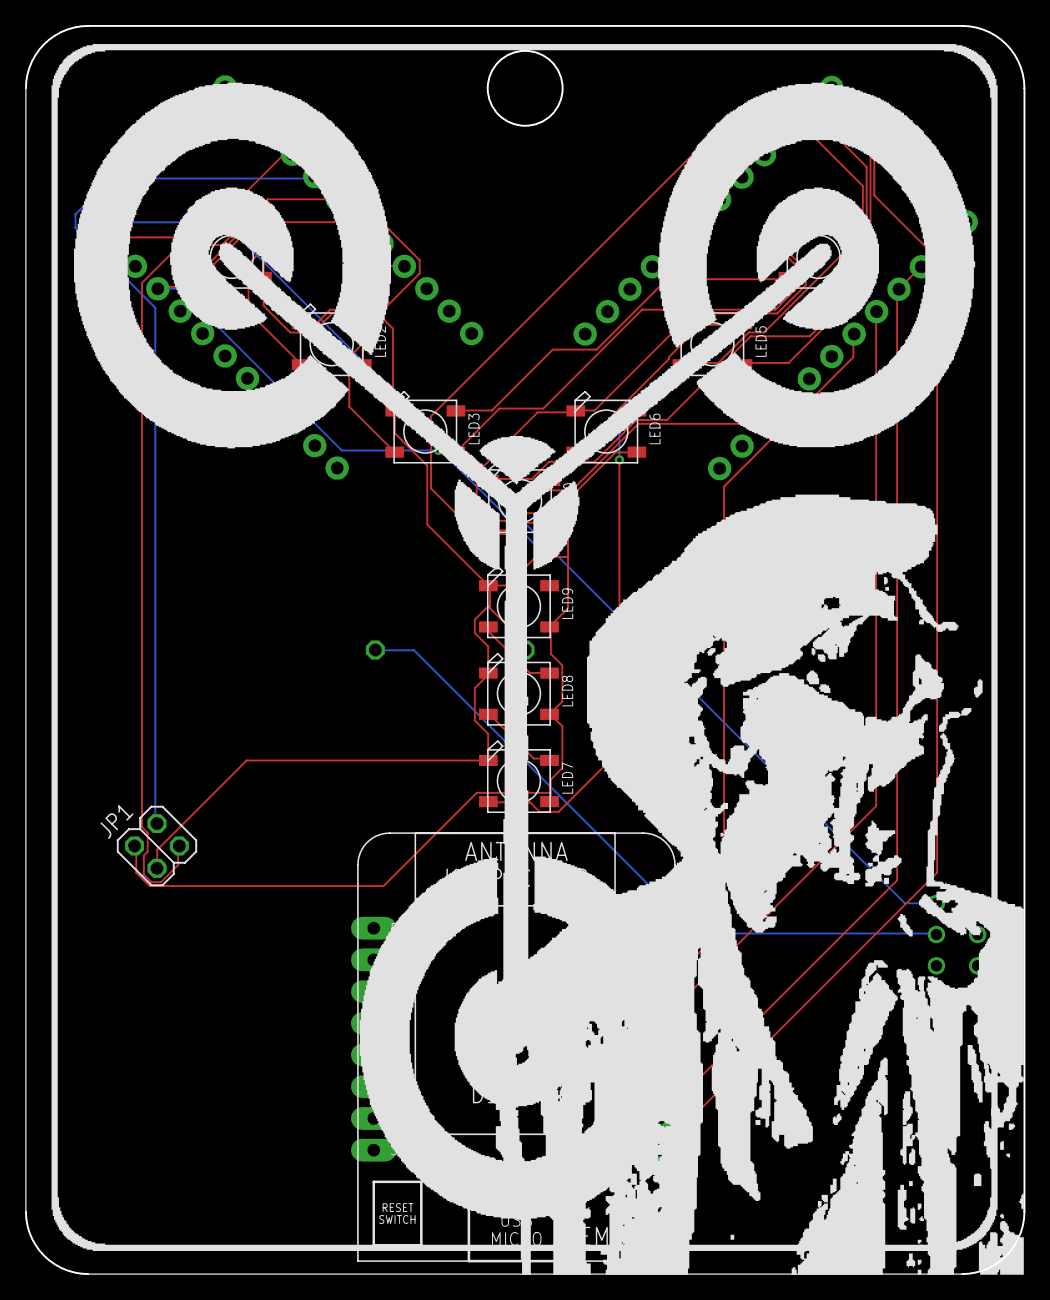
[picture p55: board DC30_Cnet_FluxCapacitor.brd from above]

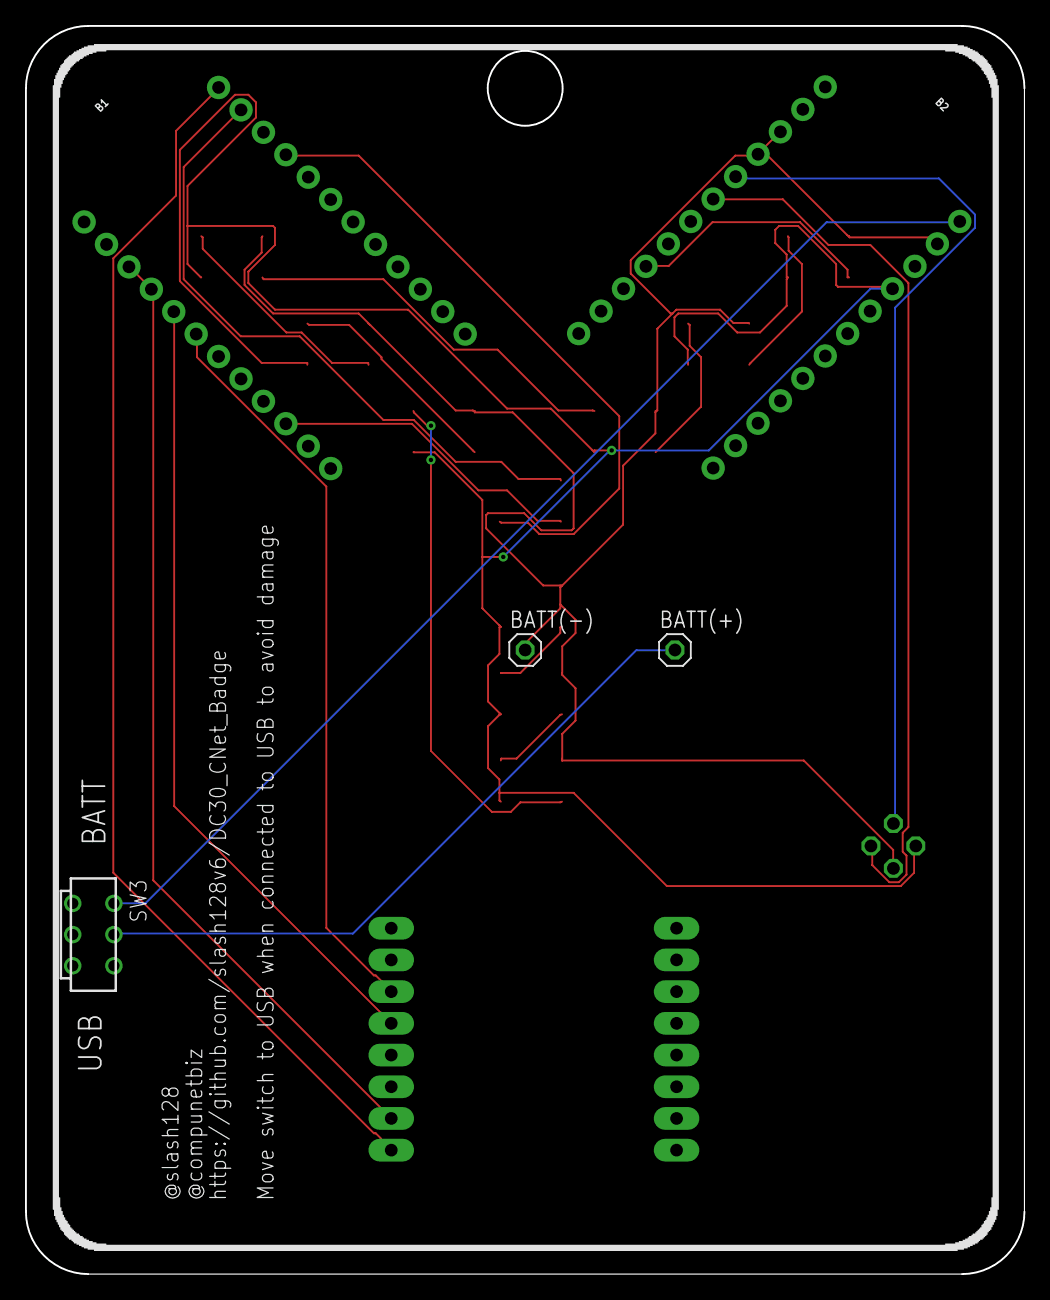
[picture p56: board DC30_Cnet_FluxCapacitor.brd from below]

Board: 2 copper layers, 80.0 x 100.0 mm, 17 parts (5 on the bottom side), 22 nets.

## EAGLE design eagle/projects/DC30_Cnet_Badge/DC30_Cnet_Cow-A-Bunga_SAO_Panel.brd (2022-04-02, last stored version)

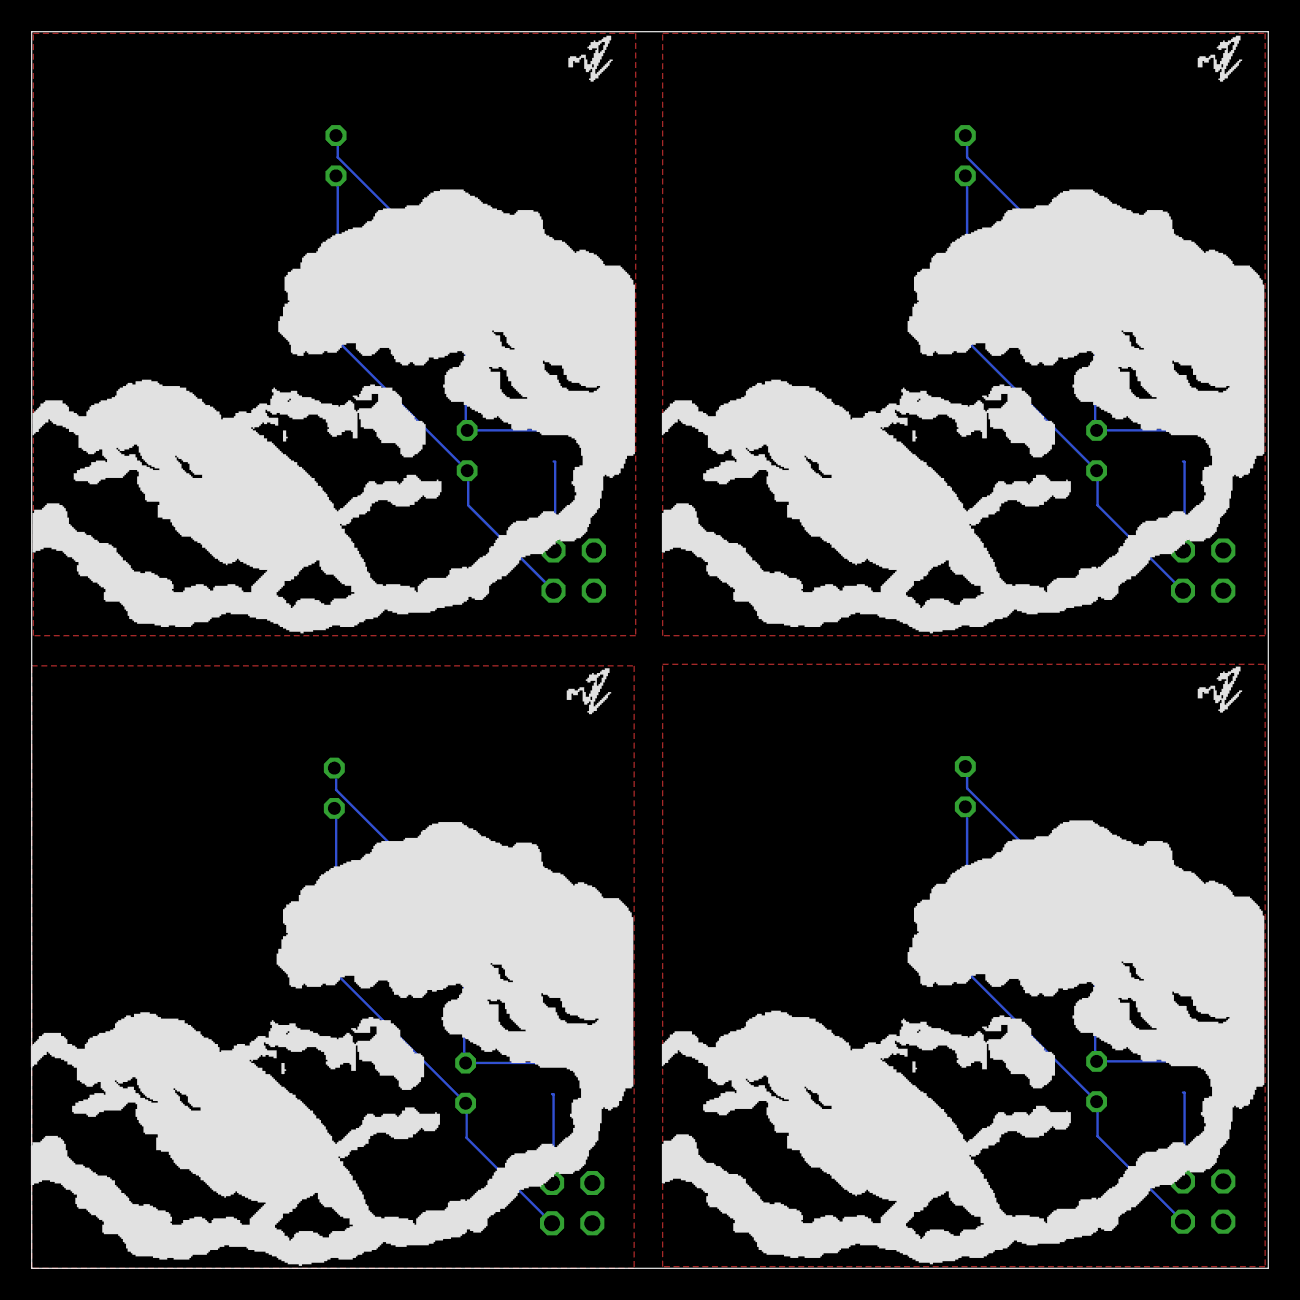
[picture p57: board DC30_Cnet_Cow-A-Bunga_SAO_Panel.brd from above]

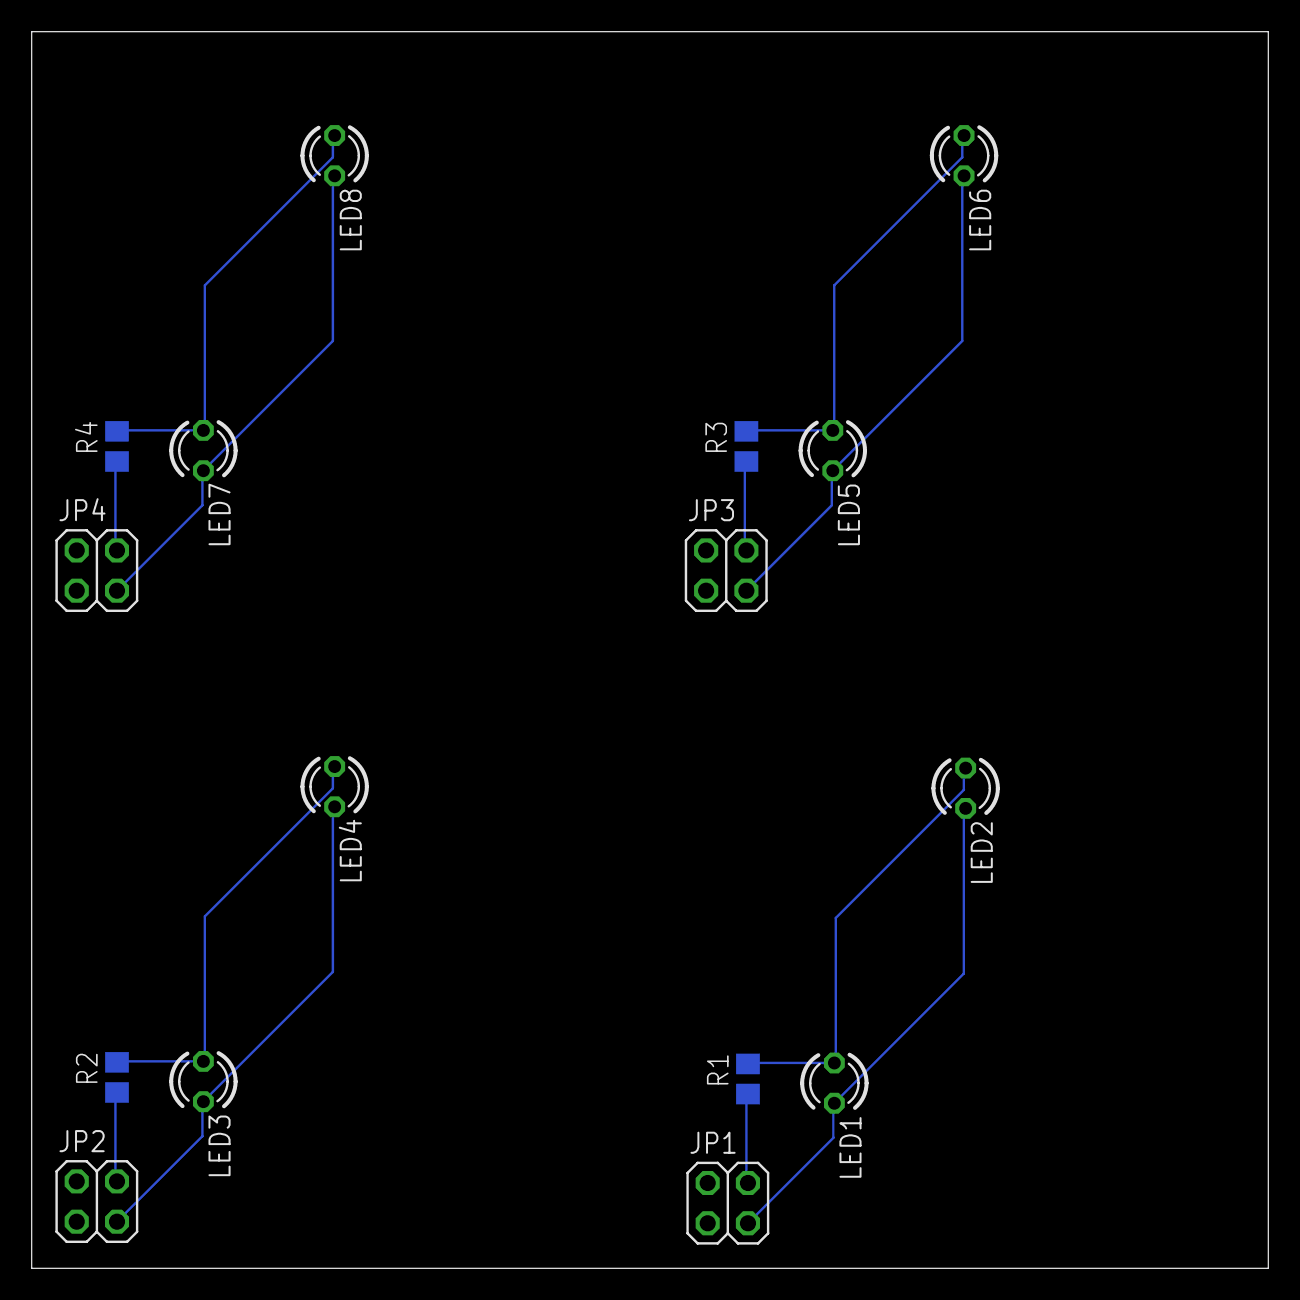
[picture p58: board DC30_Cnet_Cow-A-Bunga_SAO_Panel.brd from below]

Board: 2 copper layers, 78.0 x 78.0 mm, 16 parts (16 on the bottom side), 12 nets.

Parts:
JP1, JP2, JP3, JP4: 2X02
LED1, LED2, LED3, LED4, LED5, LED6, LED7, LED8: LED3MM
R1, R2, R3, R4: R0805

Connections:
unnamed: JP1.3, LED1.K, LED2.K
unnamed: JP1.4, R1.1
unnamed: JP2.3, LED3.K, LED4.K
unnamed: LED1.A, LED2.A, R1.2
unnamed: LED3.A, LED4.A, R2.2
unnamed: JP2.4, R2.1
unnamed: JP3.3, LED5.K, LED6.K
unnamed: LED5.A, LED6.A, R3.2
unnamed: JP3.4, R3.1
unnamed: JP4.3, LED7.K, LED8.K
unnamed: LED7.A, LED8.A, R4.2
unnamed: JP4.4, R4.1

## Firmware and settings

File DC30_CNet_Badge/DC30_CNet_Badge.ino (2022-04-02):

#include <Adafruit_NeoPixel.h>
#ifdef __AVR__
  #include <avr/power.h>
#endif

#define PIN 6
#define LEVEL	10

// Parameter 1 = number of pixels in strip
// Parameter 2 = Arduino pin number (most are valid)
// Parameter 3 = pixel type flags, add together as needed:
//   NEO_KHZ800  800 KHz bitstream (most NeoPixel products w/WS2812 LEDs)
//   NEO_KHZ400  400 KHz (classic 'v1' (not v2) FLORA pixels, WS2811 drivers)
//   NEO_GRB     Pixels are wired for GRB bitstream (most NeoPixel products)
//   NEO_RGB     Pixels are wired for RGB bitstream (v1 FLORA pixels, not v2)
//   NEO_RGBW    Pixels are wired for RGBW bitstream (NeoPixel RGBW products)
Adafruit_NeoPixel strip = Adafruit_NeoPixel(9, PIN, NEO_GRB + NEO_KHZ800);

// IMPORTANT: To reduce NeoPixel burnout risk, add 1000 uF capacitor across
// pixel power leads, add 300 - 500 Ohm resistor on first pixel's data input
// and minimize distance between Arduino and first pixel.  Avoid connecting
// on a live circuit...if you must, connect GND first.

void setup() {
  // This is for Trinket 5V 16MHz, you can remove these three lines if you are not using a Trinket
  #if defined (__AVR_ATtiny85__)
    if (F_CPU == 16000000) clock_prescale_set(clock_div_1);
  #endif
  // End of trinket special code


  strip.begin();
  strip.show(); // Initialize all pixels to 'off'
}

void loop() {
  examples(LEVEL);
  rainbow(10);
  rainbowCycle(5);
  theaterChaseRainbow(50);
}

//Examples
void examples(int brightnessLevel) {
  // Some example procedures showing how to display to the pixels:
  strip.setBrightness(LEVEL);
  colorWipe(strip.Color(255, 0, 0), 50); // Red
  colorWipe(strip.Color(0, 255, 0), 50); // Green
  colorWipe(strip.Color(0, 0, 255), 50); // Blue
  colorWipe(strip.Color(255, 255, 255), 50); // White RGBW
  // Send a theater pixel chase in...
  theaterChase(strip.Color(255, 255, 255), 50); // White
  theaterChase(strip.Color(255, 0, 0), 50); // Red
  theaterChase(strip.Color(0, 0, 255), 50); // Blue
  theaterChase(strip.Color(0, 255, 0), 50); // Green
}

// Fill the dots one after the other with a color
void colorWipe(uint32_t c, uint8_t wait) {
  for(uint16_t i=0; i<strip.numPixels(); i++) {
    strip.setPixelColor(i, c);
    strip.show();
    delay(wait);
  }
}

void rainbow(uint8_t wait) {
  uint16_t i, j;

  for(j=0; j<256; j++) {
    for(i=0; i<strip.numPixels(); i++) {
	  strip.setBrightness(LEVEL);
      strip.setPixelColor(i, Wheel((i+j) & 255));
    }
    strip.show();
    delay(wait);
  }
}

// Slightly different, this makes the rainbow equally distributed throughout
void rainbowCycle(uint8_t wait) {
  uint16_t i, j;

  for(j=0; j<256*5; j++) { // 5 cycles of all colors on wheel
    for(i=0; i< strip.numPixels(); i++) {
	  strip.setBrightness(LEVEL);
      strip.setPixelColor(i, Wheel(((i * 256 / strip.numPixels()) + j) & 255));
    }
    strip.show();
    delay(wait);
  }
}

//Theatre-style crawling lights.
void theaterChase(uint32_t c, uint8_t wait) {
  for (int j=0; j<10; j++) {  //do 10 cycles of chasing
    for (int q=0; q < 3; q++) {
      for (uint16_t i=0; i < strip.numPixels(); i=i+3) {
		strip.setBrightness(LEVEL);
        strip.setPixelColor(i+q, c);    //turn every third pixel on
      }
      strip.show();

      delay(wait);

      for (uint16_t i=0; i < strip.numPixels(); i=i+3) {
		strip.setBrightness(LEVEL);
        strip.setPixelColor(i+q, 0);        //turn every third pixel off
      }
    }
  }
}

//Theatre-style crawling lights with rainbow effect
void theaterChaseRainbow(uint8_t wait) {
  for (int j=0; j < 256; j++) {     // cycle all 256 colors in the wheel
    for (int q=0; q < 3; q++) {
      for (uint16_t i=0; i < strip.numPixels(); i=i+3) {
		strip.setBrightness(LEVEL);
        strip.setPixelColor(i+q, Wheel( (i+j) % 255));    //turn every third pixel on
      }
      strip.show();

      delay(wait);

      for (uint16_t i=0; i < strip.numPixels(); i=i+3) {
		strip.setBrightness(LEVEL);
        strip.setPixelColor(i+q, 0);        //turn every third pixel off
      }
    }
  }
}

// Input a value 0 to 255 to get a color value.
// The colours are a transition r - g - b - back to r.
uint32_t Wheel(byte WheelPos) {
  WheelPos = 255 - WheelPos;
  if(WheelPos < 85) {
    return strip.Color(255 - WheelPos * 3, 0, WheelPos * 3);
  }
  if(WheelPos < 170) {
    WheelPos -= 85;
    return strip.Color(0, WheelPos * 3, 255 - WheelPos * 3);
  }
  WheelPos -= 170;
  return strip.Color(WheelPos * 3, 255 - WheelPos * 3, 0);
}

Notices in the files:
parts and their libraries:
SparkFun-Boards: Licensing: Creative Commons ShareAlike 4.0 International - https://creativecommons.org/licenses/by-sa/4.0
